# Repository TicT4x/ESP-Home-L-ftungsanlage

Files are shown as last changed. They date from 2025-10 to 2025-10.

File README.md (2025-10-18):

Bauteile:
  - 2x Artic P12 Max - PC Lüfter
  - 2x 608Z Kugellager
  - ESP32 Dev Kit
  - SG90 Servo
  - Buck Converter 
  - 12v Netzteil

Zu den 3D Druck Teilen:
Ist alles etwas tight, also je nach tolleranzen vom Drucker kann es etwas gewalt benötigen, um die sachen zusammen zu bekommen. Hält dafür aber ohne Kleber ^^
Der Servoadapter ist nötig, da der Servo von unten durch die Basisplatte gesteckt wird und von oben verschraubt. Der Adapter dient also zum Kontern der schraube von Oben.

Zu den PC Lüfter:
Ich hab drauf geachtet welche zu nehmen, die PWM gesteuert sind und auch über PWM ausgeschaltet werden können. Solltest du andere nehmen, achte darauf, dass die das auch haben. 

Code ist in der YAML Datei. Würde den nur als Inspiration nutzen, ESP Home generiert ja auch eigene dinge bei ner neuen Datei.
Was wichtig ist beim Code: Manche PWM Lüfter brauchen ein open_drain. Wenn man den weg lässt, lassen sich die Lüfter nicht richtig steuern.

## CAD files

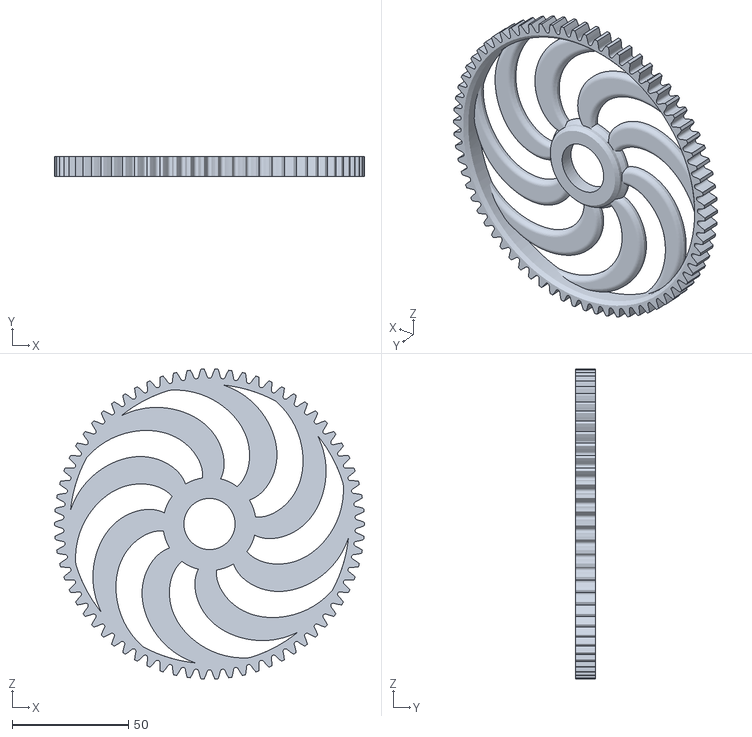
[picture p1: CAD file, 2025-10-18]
Finne.stl
133.2 x 8.50 x 133.1

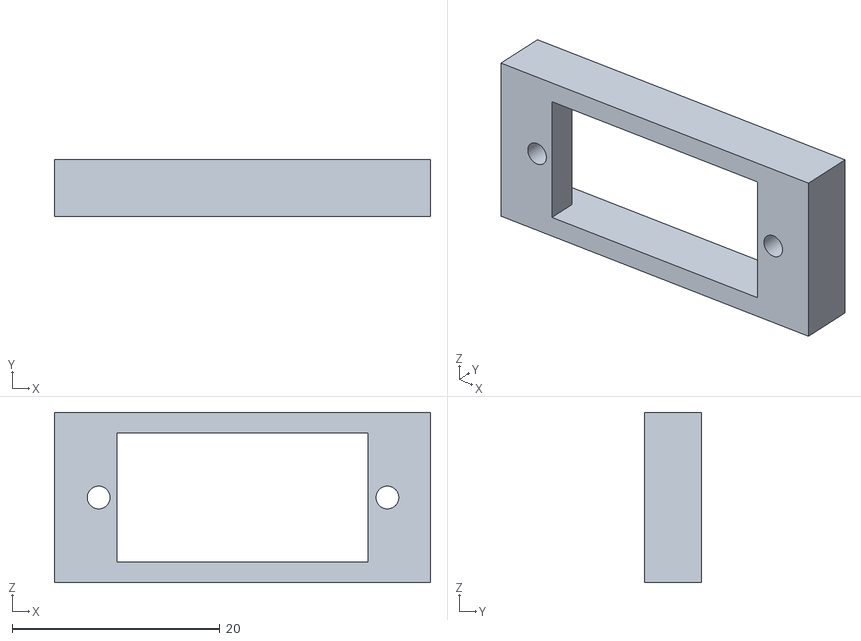
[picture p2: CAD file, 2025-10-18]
Servoadapter.stl
36.2 x 5.50 x 16.4

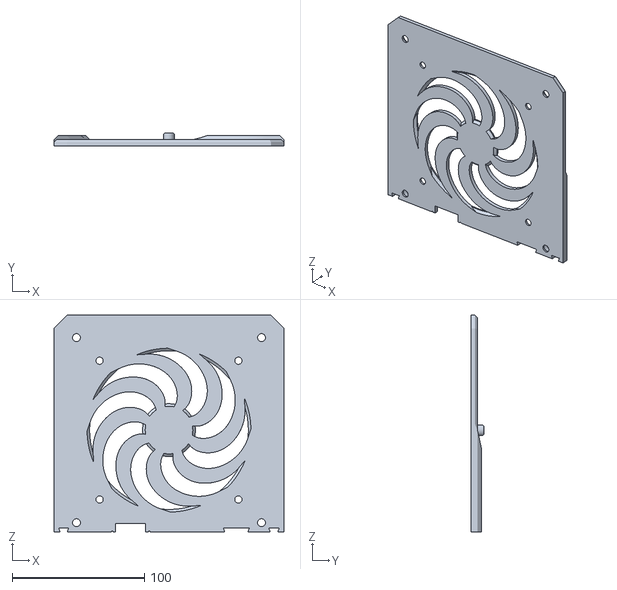
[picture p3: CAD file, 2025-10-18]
Basisplatte Rechts.stl
174.0 x 10.0 x 164.0

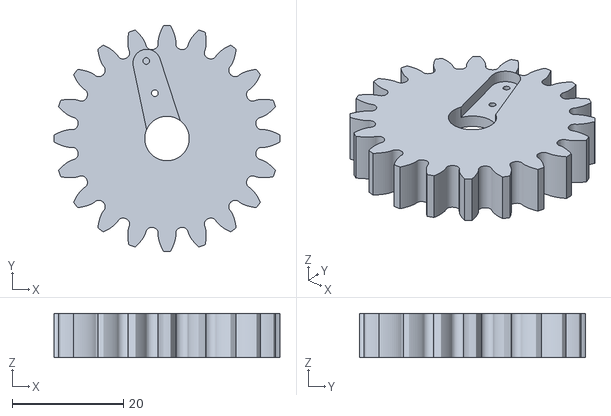
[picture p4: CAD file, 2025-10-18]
Zahnrad Servo.stl
40.7 x 40.7 x 8.00

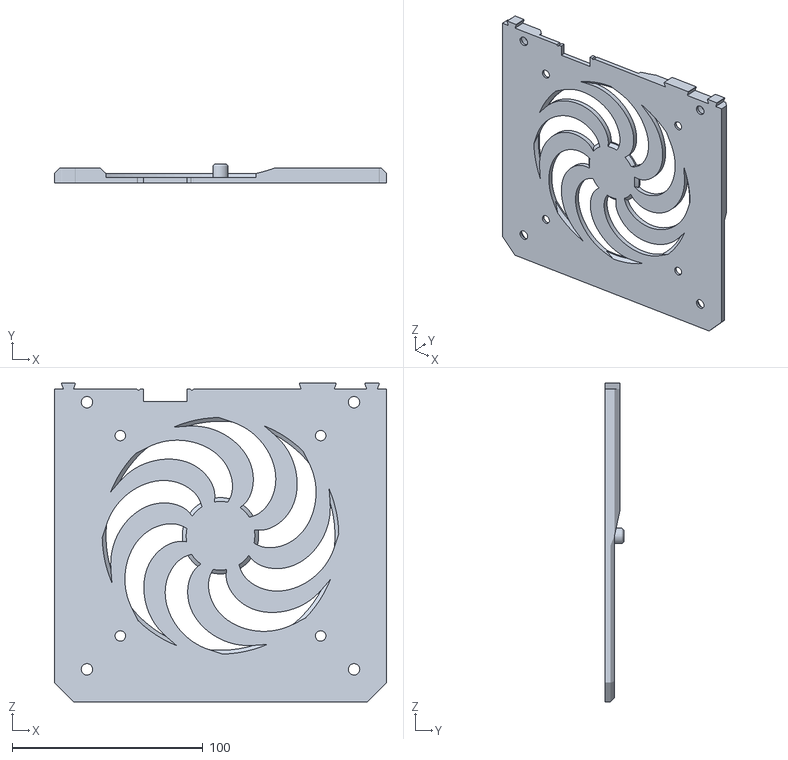
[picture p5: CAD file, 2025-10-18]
Basisplatte Links.stl
174.0 x 10.0 x 167.0

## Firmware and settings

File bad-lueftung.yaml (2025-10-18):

esphome:
  name: bad-luftung
  friendly_name: Bad Lüftung

esp32:
  board: esp32dev
  framework:
    type: esp-idf

# Enable logging
logger:

# Enable Home Assistant API
api:
  encryption:
    key: "Your Key"

ota:
  - platform: esphome
    password: "Your Passwort"

wifi:
  ssid: !secret wifi_ssid
  password: !secret wifi_password

  manual_ip:
    static_ip: 192.168.0.XX
    gateway: 192.168.0.1
    subnet: 255.255.255.0
    
  # Enable fallback hotspot (captive portal) in case wifi connection fails
  ap:
    ssid: "Bad-Luftung Fallback Hotspot"
    password: "Your Passwort"


captive_portal:
sensor:
  - platform: pulse_counter
    pin: GPIO14
    name: FAN 1 RPM
    id: fan_1_pulse
    unit_of_measurement: 'RPM'
    filters:
      - multiply: 0.5
    count_mode:
      rising_edge: INCREMENT
      falling_edge: DISABLE
    update_interval: 3s

  - platform: pulse_counter
    pin: GPIO27
    name: FAN 2 RPM
    id: fan_2_pulse
    unit_of_measurement: 'RPM'
    filters:
      - multiply: 0.5
    count_mode:
      rising_edge: INCREMENT
      falling_edge: DISABLE
    update_interval: 3s

  - platform: dht
    pin: GPIO25
    temperature:
      name: "Bad Temperatur"
    humidity:
      name: "Bad Luftfeuchtigkeit"
    update_interval: 60s

servo:
  - id: my_servo
    output: pwm_output
    transition_length: 5s

output:
#Fans

  - platform: ledc
    pin: 
      number: GPIO13
      mode:
        output: true
        open_drain: true

    frequency: 23000 Hz #25000
    id: fanhub_pwm
    channel: 4

#servo
  - platform: ledc
    id: pwm_output
    pin: GPIO26
    frequency: 50 Hz
    channel: 2

fan:
  - platform: speed
    output: fanhub_pwm
    name: "PWM Fan"

    on_turn_on:
      - switch.turn_on: servo_fan
    on_turn_off:
      - switch.turn_off: servo_fan


switch:
  - platform: template
    name: "Lüftungsklappe"
    id: servo_fan
    optimistic: true

    turn_on_action: 
      - servo.write:
          id: my_servo
          level: 0.80

    turn_off_action: 
      - servo.write:
          id: my_servo
          level: -0.12
